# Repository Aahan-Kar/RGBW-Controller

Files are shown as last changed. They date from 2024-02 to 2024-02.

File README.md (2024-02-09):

# RGBW LED Strip Controller


Welcome to the repository for the RGBW LED Strip Controller! This project is designed for enthusiasts and professionals looking to control non-addressable RGBW LED strips with precision and flexibility. Using a Teensy 3.2 microcontroller, this controller offers high-frequency PWM for smooth LED dimming, compatibility with both RGB and single-color strips, and both manual and software control options.

## Features

- **High-Frequency PWM**: The controller operates at a 23.4 kHz PWM frequency to minimize visible flicker, ensuring smooth light output.
- **Compatibility**: Designed for use with non-addressable RGBW LED strips, but also supports RGB and single-color (white) strips.
- **12V Input**: Supports a 12V input for LED driving and internal electronics, ensuring wide compatibility with common LED strip specifications.
- **Power Control**: Includes a power on/off switch for easy power management.
- **Manual Control**: Features four knobs for adjusting the brightness levels of the Red, Green, Blue, and White channels independently.
- **USB Connectivity**: Offers USB connectivity for software control, making it suitable for integration with computer-managed setups like 3D printers with Raspberry Pi controllers.
- **Mode Selection**: A rocker switch allows for easy toggling between manual (hardware) control and software control modes.

## Repository Contents

- `Eagle/` - Contains Eagle CAD files including both the electronic schematics and PCB layout designs in a single directory, as preferred by Eagle CAD.
- `Gerber/` - Gerber files ready for PCB fabrication.
- `Code/` - Source code for the Teensy 3.2 microcontroller, including the PWM control and USB communication logic.
- `3DCAD/` - 3D CAD files for the controller's enclosure, suitable for 3D printing.

## Getting Started

### Hardware Setup

1. **Power Supply Connection**: Connect a 12V power supply to the barrel connector. Ensure your power supply can handle the current draw of your LED setup.
2. **Power On**: Use the power switch to turn on the controller.
3. **LED Strip Connection**: Connect your RGBW, RGB, or White LED strip to the appropriate terminals on the controller.

### Manual Control

- With the mode selector switched to hardware control, use the knobs on the controller to adjust the brightness levels of each channel to your liking.

### Software Control

- Ensure the mode selector is set to software control.
- Connect the controller to your computer via USB. It should be recognized as a serial (RS232) device.
- You can now send commands from your computer to adjust the LED strip's settings. This is particularly useful for automated setups like lighting effects for 3D printers.

## Contributing

Contributions to this project are welcome! Whether it's bug fixes, feature enhancements, or documentation improvements, please feel free to fork the repository and submit a pull request.

## License

This project is released under the [MIT License](LICENSE.md). Feel free to use, modify, and distribute the code and designs as per the license terms.

## Contact

For questions, suggestions, or to report issues, please open an issue in this repository, and we'll get back to you as soon as possible.

Happy Lighting!

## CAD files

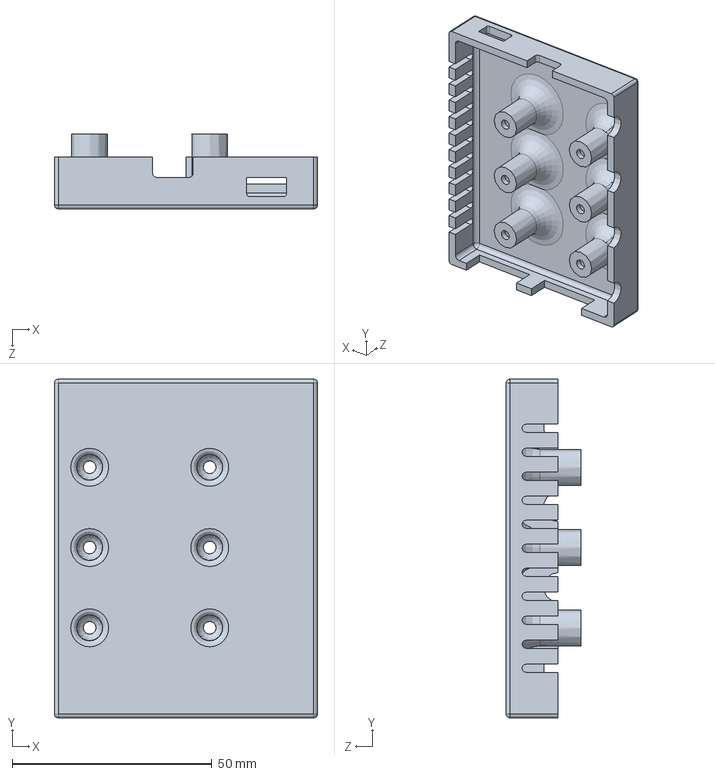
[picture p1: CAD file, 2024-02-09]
3DCAD/BoxTop.SLDPRT
65.9 x 84.8 x 18.8 mm

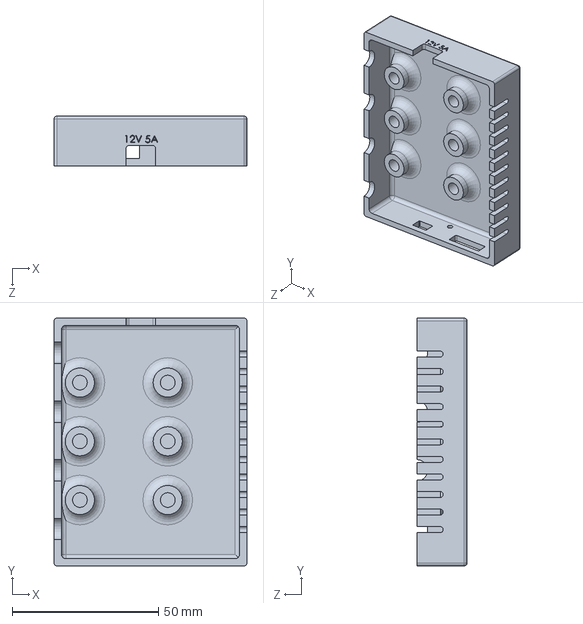
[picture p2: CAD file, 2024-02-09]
3DCAD/BoxBottom.SLDPRT
65.9 x 84.8 x 17.1 mm

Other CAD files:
3DCAD/STLs/BoxBottom.STL
3DCAD/STLs/BoxTop.STL

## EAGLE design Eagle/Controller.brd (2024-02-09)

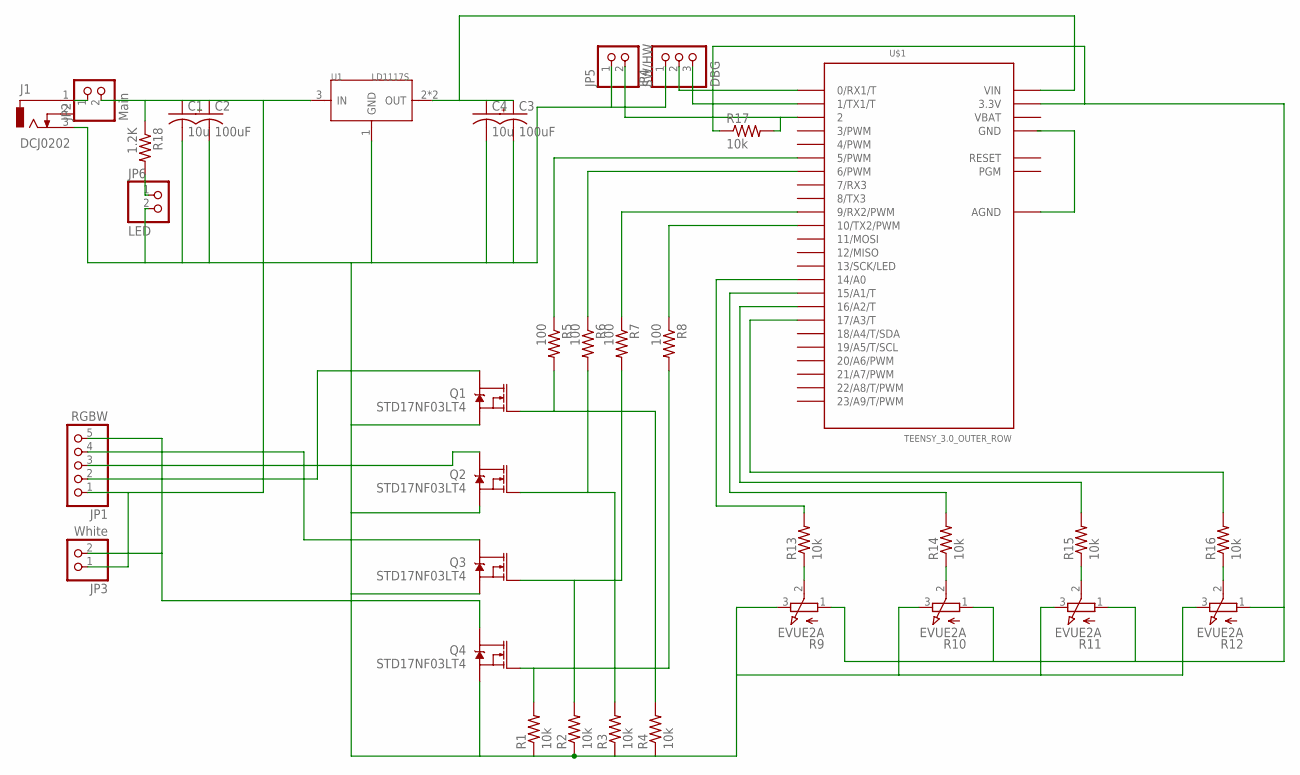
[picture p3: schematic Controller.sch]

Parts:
C1, C4: 10u; ADAFRUIT_C0805
C2, C3: 100uF; RCL_TT2D6
J1: DCJ0202
JP1: RGBW; 1X05/90
JP2: Main; 1X02
JP3: White; 1X02/90
JP4: DBG; 1X03/90
JP5: SW/HW; 1X02
JP6: LED; 1X02
Q1, Q2, Q3, Q4: STD17NF03LT4; DPAK
R1, R2, R3, R4, R13, R14, R15, R16, R17: 10k; R0805
R5, R6, R7, R8: 100; R0805
R9, R10, R11, R12: EVUE2A; EVUE
R18: 1.2K; R0805
U1: LD1117S; SOT-223
U$1: TEENSY_3.0_OUTER_ROW; TEENSY_3.0-3.2&LC_OUTER_ROW

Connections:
GND: C1.2, C2.-, C3.-, C4.2, J1.3, JP4.1, JP5.1, JP6.2, Q1.3 (S), Q2.3 (S), Q3.3 (S), Q4.3 (S), R1.1, R2.1, R3.1, R4.1, R9.3 (E), R10.3 (E), R11.3 (E), R12.3 (E), U1.1 (GND), U$1.GND, U$1.GND1 (GND)
unnamed: C1.1, C2.+, JP1.1, JP2.2, JP3.1, R18.1, U1.3 (IN)
unnamed: C3.+, C4.1, U1.2 (OUT), U1.TER (OUT), U$1.VIN
unnamed: R5.1, U$1.5 (5/PWM)
unnamed: Q4.1 (G), R1.2, R8.2
unnamed: Q3.1 (G), R2.2, R7.2
unnamed: Q2.1 (G), R3.2, R6.2
unnamed: Q1.1 (G), R4.2, R5.2
unnamed: R6.1, U$1.6 (6/PWM)
unnamed: R7.1, U$1.9 (9/RX2/PWM)
unnamed: R8.1, U$1.10 (10/TX2/PWM)
unnamed: R9.2 (S), R13.1
unnamed: JP1.2, Q1.4 (D)
unnamed: JP1.3, Q2.4 (D)
unnamed: JP1.4, Q3.4 (D)
unnamed: JP1.5, JP3.2, Q4.4 (D)
unnamed: J1.1, JP2.1
unnamed: R10.2 (S), R14.1
unnamed: R11.2 (S), R15.1
unnamed: R12.2 (S), R16.1
unnamed: R9.1 (A), R10.1 (A), R11.1 (A), R12.1 (A), R17.1, U$1.3.3V, U$1.3.3V1 (3.3V)
unnamed: R13.2, U$1.14/A0
unnamed: R14.2, U$1.15/A1 (15/A1/T)
unnamed: R15.2, U$1.16/A2 (16/A2/T)
unnamed: R16.2, U$1.17/A3 (17/A3/T)
unnamed: JP5.2, R17.2, U$1.2
unnamed: JP4.2, U$1.0 (0/RX1/T)
unnamed: JP4.3, U$1.1 (1/TX1/T)
unnamed: JP6.1, R18.2
VBAT: U$1.VBAT

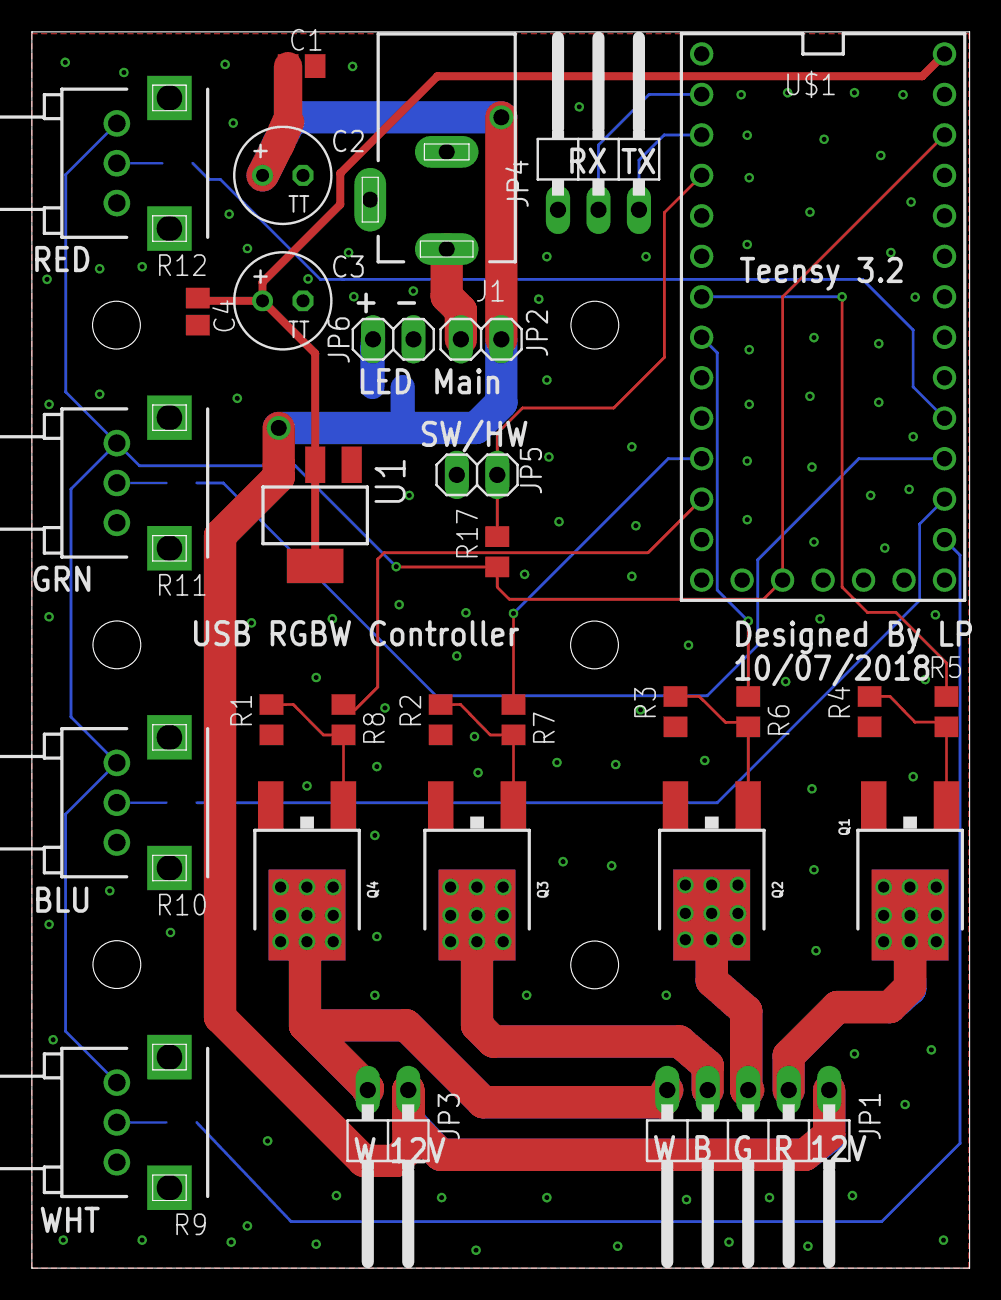
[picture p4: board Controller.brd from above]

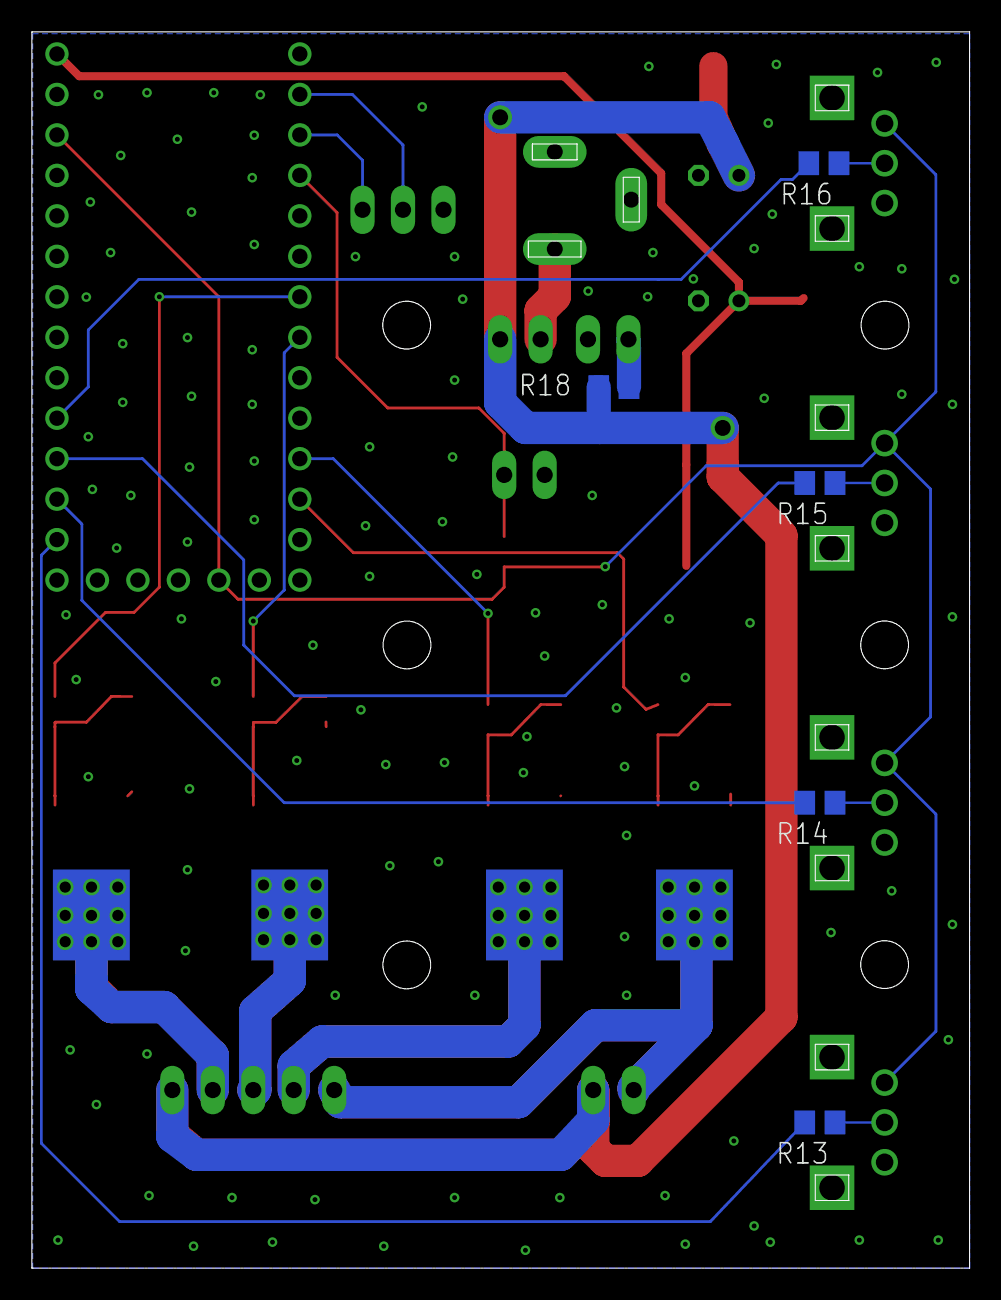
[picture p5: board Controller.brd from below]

Board: 2 copper layers, 58.9 x 77.6 mm, 35 parts (5 on the bottom side), 29 nets.

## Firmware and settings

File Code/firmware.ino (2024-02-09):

#define WhiteKnob 0
#define BlueKnob 1
#define GreenKnob 2
#define RedKnob 3
#define swhwSwitch 2
#define differsby 4   //As the analog value fluctuates quite a lot this is how much the new value has to differ from the olv value to be considered as new value
#define WhitePWMPin 10
#define BluePWMPin 9
#define GreenPWMPin 6
#define RedPWMPin 5

int WhiteBrightness=0;
int BlueBrightness=0;
int GreenBrightness=0;
int RedBrightness=0;
bool TypeOfControl=false;    //false means HW control true means sofrware control
bool ControlOverride = false; //Allow the software to override the control if necessary. Toggling the HW/SW switch should clear this flag.


void setup()
{                
  pinMode(swhwSwitch, INPUT);
  analogWriteResolution(11);
  analogWriteFrequency(RedPWMPin, 23437.5);
  analogWriteFrequency(GreenPWMPin, 23437.5);
  analogWriteFrequency(BluePWMPin, 23437.5);
  analogWriteFrequency(WhitePWMPin, 23437.5);

  RedBrightness=(analogRead(RedKnob)*2047)/1023;
  analogWrite(RedPWMPin,2047-RedBrightness);         //My Potentiometers are wires to decrease in voltage on clockwise turn. As it seems counter intuitive I just ionvert in the software
  GreenBrightness=(analogRead(GreenKnob)*2047)/1023;
  analogWrite(GreenPWMPin,2047-GreenBrightness);
  BlueBrightness=(analogRead(BlueKnob)*2047)/1023;
  analogWrite(BluePWMPin,2047-BlueBrightness);
  WhiteBrightness=(analogRead(WhiteKnob)*2047)/1023;
  analogWrite(WhitePWMPin,2047-WhiteBrightness);
  Serial.begin(9600);
}

void loop()                     
{
  if(digitalRead(swhwSwitch)==1)    //the switch is open. Pin 2 is wired for active low
    TypeOfControl=false;
  else
    TypeOfControl=true;

  //if(!TypeOfControl)        //i.e. it's under hardware control
  //{
     int val = 0;
     val=(analogRead(RedKnob)*2047)/1023;
     if(abs(RedBrightness-val)>differsby)
     {
       RedBrightness =val;
       Serial.print("RedBrightness=");
       Serial.println(RedBrightness);
       analogWrite(RedPWMPin,2047-RedBrightness);         //My Potentiometers are wires to decrease in voltage on clockwise turn. As it seems counter intuitive I just ionvert in the software
     }

     val=(analogRead(GreenKnob)*2047)/1023;
     if(abs(GreenBrightness-val)>differsby)
     {
        GreenBrightness=val;
        Serial.print("GreenBrightness=");
        Serial.println(GreenBrightness);
        analogWrite(GreenPWMPin,2047-GreenBrightness);
     }

     val=(analogRead(BlueKnob)*2047)/1023;
     if(abs(BlueBrightness-val)>differsby)
     {
        BlueBrightness=val;
        Serial.print("BlueBrightness=");
        Serial.println(BlueBrightness);
        analogWrite(BluePWMPin,2047-BlueBrightness);
     }

     val=(analogRead(WhiteKnob)*2047)/1023;
     if(abs(WhiteBrightness-val)>differsby)
     {
        WhiteBrightness=val;
        Serial.print("WhiteBrightness=");
        Serial.println(WhiteBrightness); 
        analogWrite(WhitePWMPin,2047-WhiteBrightness);
     }         
    
  //}
  //Serial.println(val);
  //delay(250);
}

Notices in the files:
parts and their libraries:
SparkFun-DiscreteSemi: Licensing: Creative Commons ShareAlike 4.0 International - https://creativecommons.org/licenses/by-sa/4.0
